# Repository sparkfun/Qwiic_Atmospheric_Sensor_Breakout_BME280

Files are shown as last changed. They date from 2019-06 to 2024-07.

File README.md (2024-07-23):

SparkFun Atmospheric Sensor Breakout - BME280 (Qwiic)
========================================

SparkFun Atmospheric Sensor Breakout - BME280 (Qwiic)

[*SparkFun Atmospheric Sensor Breakout - BME280 (Qwiic) (SEN-15440)*](https://www.sparkfun.com/products/15440)

The SparkFun Atmospheric Sensor Breakout - BME280 (Qwiic) is perfect for sensing basic weather information. Using I2C, you can easily read data from the on-board BME280 sensor. This includes temperature, pressure, altitude and humidity.

Repository Contents
-------------------
* **/Hardware** - Eagle design files (.brd, .sch)
* **/Production** - Production panel files (.brd)

Documentation
--------------
* **[Arduino Library](https://github.com/sparkfun/SparkFun_BME280_Arduino_Library/)** - Arduino library for the BME280.
* **[Python Library](https://github.com/sparkfun/Qwiic_BME280_Py)** - Python library for the BME280.
* **[Fritzing Part](https://github.com/sparkfun/Fritzing_Parts/tree/main/products/15440_sfe_qwiic_atmospheric_sensor_BME280_pressure_humidity_temperature.fzpz)** - Fritzing part for the Qwiic BME280
* **[Hookup Guide](https://learn.sparkfun.com/tutorials/qwiic-atmospheric-sensor-bme280-hookup-guide)** - Basic hookup guide for the SparkFun Atmospheric Sensor Breakout - BME280 (Qwiic).
* **[Qwiic Ecosystem](https://www.sparkfun.com/qwiic)** - Qwiic enabled for fast prototyping!

Product Versions
----------------
* [SEN-13676](https://www.sparkfun.com/products/13676)- SparkFun Atmospheric Sensor Breakout - BME280
* [SEN-15440](https://www.sparkfun.com/products/15440)- SparkFun Atmospheric Sensor Breakout - BME280 (Qwiic).

License Information
-------------------

This product is _**open source**_! 

Please review the LICENSE.md file for license information. 

If you have any questions or concerns on licensing, please contact technical support on our [SparkFun forums](https://forum.sparkfun.com/viewforum.php?f=152).

Distributed as-is; no warranty is given.

- Your friends at SparkFun.

_<COLLABORATION CREDIT>_

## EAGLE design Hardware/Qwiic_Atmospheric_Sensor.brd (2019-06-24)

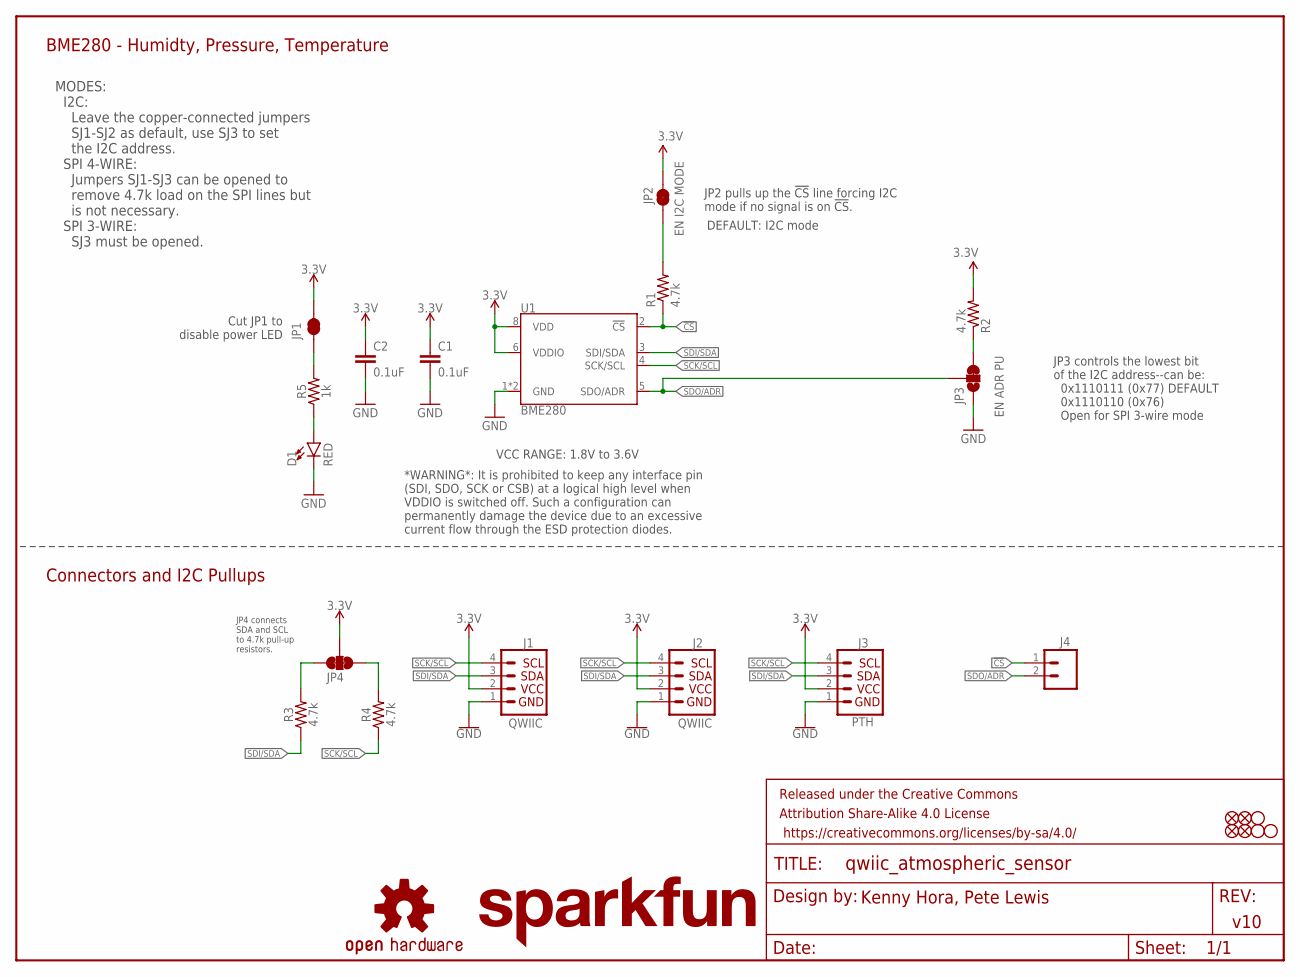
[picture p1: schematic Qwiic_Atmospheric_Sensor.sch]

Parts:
C1, C2: 0.1uF; 0603
D1: RED; LED-0603
FD1, FD2, FD3, FD4: FIDUCIAL1X2; FIDUCIAL-1X2
FRAME1: FRAME-LETTER; CREATIVE_COMMONS
H1, H2, H4: STAND-OFF
J1, J2: QWIIC; JST04_1MM_RA
J3: PTH; 1X04_NO_SILK
J4: CONN_021X02_NO_SILK; 1X02_NO_SILK
JP1: JUMPER-SMT_2_NC_TRACE_NO-SILK; SMT-JUMPER_2_NC_TRACE_NO-SILK
JP2: EN I2C MODE; PAD-JUMPER-2-NC_BY_TRACE_NO_SILK
JP3: EN ADR PU; SMT-JUMPER_3_1-NC_TRACE_NO-SILK
JP4: JUMPER-SMT_3_2-NC_TRACE_NO-SILK; SMT-JUMPER_3_2-NC_TRACE_NO-SILK
LOGO1: SFE_LOGO_NAME.1_INCH; SFE_LOGO_NAME_.1
LOGO4: OSHW-LOGOS; OSHW-LOGO-S
R1, R2, R3, R4: 4.7k; 0603
R5: 1k; 0603
U1: BME280; LGA-8-2.5X2.5

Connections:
3.3V: C1.1, C2.1, J1.2, J2.2, J3.2, JP1.2, JP2.2, JP4.2, R2.2, U1.6 (VDDIO), U1.8 (VDD)
!CS: J4.1, R1.1, U1.2 (!CS)
GND: C1.2, C2.2, D1.C, J1.1, J2.1, J3.1, JP3.1, U1.1 (GND), U1.7 (GND)
unnamed: JP3.3, R2.1
unnamed: D1.A, R5.1
unnamed: JP4.3, R3.2
unnamed: JP4.1, R4.2
unnamed: JP2.1, R1.2
unnamed: JP1.1, R5.2
SCK/SCL: J1.4, J2.4, J3.4, R4.1, U1.4 (SCK/SCL)
SDI/SDA: J1.3, J2.3, J3.3, R3.1, U1.3 (SDI/SDA)
SDO/ADR: J4.2, JP3.2, U1.5 (SDO/ADR)

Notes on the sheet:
JP4 connects SDA and SCL to 4.7k pull-up resistors.
v10
Kenny Hora, Pete Lewis
DEFAULT: I2C mode
BME280 - Humidty, Pressure, Temperature
JP2 pulls up the !CS! line forcing I2C mode if no signal is on !CS!.
JP3 controls the lowest bit of the I2C address--can be: 0x1110111 (0x77) DEFAULT 0x1110110 (0x76) Open for SPI 3-wire mode
MODES: I2C: Leave the copper-connected jumpers SJ1-SJ2 as default, use SJ3 to set the I2C address. SPI 4-WIRE: Jumpers SJ1-SJ3 can be opened to remove 4.7k load on the SPI lines but is not necessary. SPI 3-WIRE: SJ3 must be opened.
VCC RANGE: 1.8V to 3.6V
Connectors and I2C Pullups
Cut JP1 to disable power LED
*WARNING*: It is prohibited to keep any interface pin (SDI, SDO, SCK or CSB) at a logical high level when VDDIO is switched off. Such a configuration can permanently damage the device due to an excessive current flow through the ESD protection diodes.

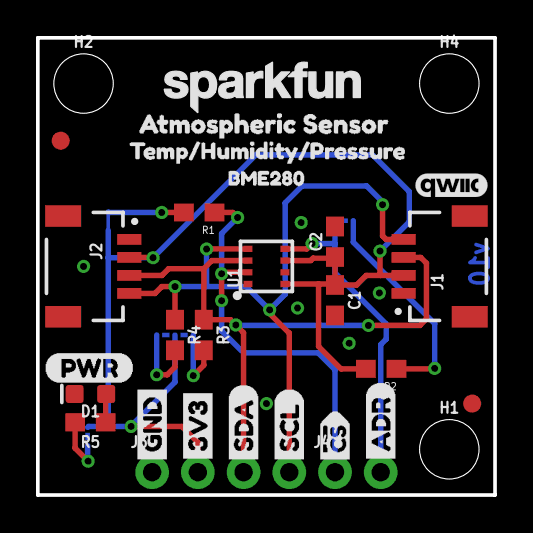
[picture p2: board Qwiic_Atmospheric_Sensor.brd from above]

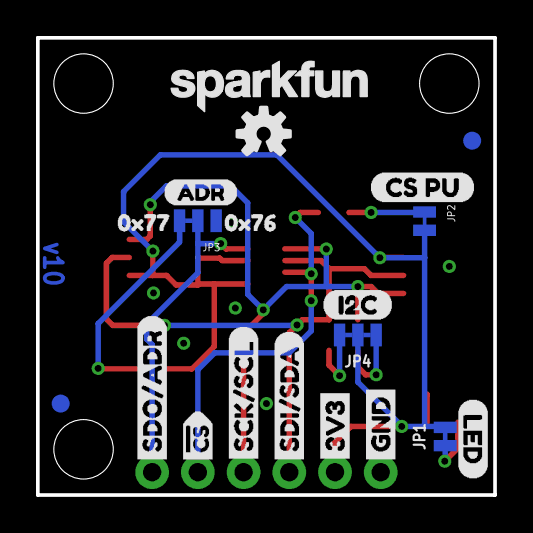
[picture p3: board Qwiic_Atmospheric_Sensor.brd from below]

Board: 2 copper layers, 25.4 x 25.4 mm, 51 parts (20 on the bottom side), 12 nets.

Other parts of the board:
LOGO3: SFE_LOGO_NAME.1_INCH; SFE_LOGO_NAME_.1@1
U$1: LED0
U$2, U$7: 3V34
U$3: ADR8
U$4, U$8: GND3
U$5: SDA5
U$6: SCL6
U$9: SDI#SDA11
U$10: SDO#ADR9
U$11: SCK#SCL10
U$13: PWR0
U$14, U$24: #CS0
U$15: BME2804
U$16: QWIIC_4MM
U$17: ATMOSPHERIC_SENSOR0
U$18: ADR2
U$19: 0X771
U$20: 0X760
U$21: CS_PU1
U$22: I2C0
U$23: TEMP#HUMIDITY#PRESSURE0

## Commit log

2019-06-17 switch to BME280
    [Qwiic_Weather.brd, Qwiic_Weather.sch]
2019-06-18 added SPI cabability and some prelim buzzard label work
    [Qwiic_Weather.brd, Qwiic_Weather.sch]
2019-06-19 Started routing board
    About 50% done. Added a power LED, adjusted silk.
    [Qwiic_Weather.brd, Qwiic_Weather.sch]
2019-06-19 Finished Layout
    Finished Routing and Added pin and jumper labels.
    [Qwiic_Weather.brd, Qwiic_Weather.sch]
2019-06-19 some small tweaks
    upped traces to 12 mil, nudged to avoid drc errors, added gnd via under connector.
    [Qwiic_Weather.brd]
2019-06-20 layout and library update work
    -updated 4.7K resistors to newest device (no silk under part).
    -removed some unncessary vis on 3.3V net, and rerouted.
    -nudges some traces and power LED for more efficient routing and better GND flow.
    -Moved Jumpers to no silk packages (for consistency)
    [Qwiic_Weather.brd, Qwiic_Weather.sch]
2019-06-21 changes during checklist run 1
    -moved all text in sch to vector
    -removed unwanted value on jumper
    -4pin pth connector replaced with sparkfun library
    -vcc range added
    -dimension width to 8 mils
    -updated package on IC to fatten up silk width
    -measures to inch
    -Designer added to tdocu in brd
    -nudged via to avoid silk on I2C label
    [Qwiic_Weather.brd, Qwiic_Weather.sch]
2019-06-21 Changes during/post group design review
    -added power led disable jumper (and buzzard label and schematic text note).
    -switched CS to "pointer" flag label cuz it's an input.
    -added GND vias and nudges vias for better ground flow.
    -changed info line to short dash.
    -added text name for bottom half of schematic.
    -moved fids added third standoff.
    -Capitalized Temp Humidity Pressure text.
    [Qwiic_Weather.brd, Qwiic_Weather.sch]
2019-06-24 Post double-check changes
    -added IO warning in schematic
    -removed leftover CCS811 text object in tNames
    -designer name to vector
    [Qwiic_Weather.brd, Qwiic_Weather.sch]
2019-08-21 Matching to product name
    [Qwiic_Atmospheric_Sensor.brd]
2019-08-21 Matching product name
    [Qwiic_Atmospheric_Sensor.sch]
2019-08-21 Update
    Relink photo and hookup guide, add python library, linked original breakout board

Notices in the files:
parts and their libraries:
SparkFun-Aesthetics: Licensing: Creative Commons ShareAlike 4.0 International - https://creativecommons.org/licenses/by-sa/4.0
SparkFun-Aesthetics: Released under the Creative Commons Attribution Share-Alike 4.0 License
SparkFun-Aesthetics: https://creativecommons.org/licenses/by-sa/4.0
